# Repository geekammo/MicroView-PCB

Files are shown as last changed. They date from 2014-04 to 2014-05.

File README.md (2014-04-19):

MicroView: Chip-sized Arduino with built-in OLED Display!
================================
Designed by : [Geek Ammo](http://geekammo.com) & [SparkFun Electronics](http://www.sparkfun.com)

MicroView on finger

Summary
-------
The MicroView is the first chip-sized Arduino compatible that lets you see what your Arduino is thinking using a built-in OLED display.

Description
-----------
MicroView pinout

You've never seen an Arduino™ compatible like this. With a built-in OLED (Organic Light Emitting Diode Display) you can see what your Arduino is thinking without having to connect it to your computer. 

No more cryptic "Hello World" LED blink sequences or shoehorning oversized displays onto your tiny Arduino™. Development is much easier when you can see what's going on.

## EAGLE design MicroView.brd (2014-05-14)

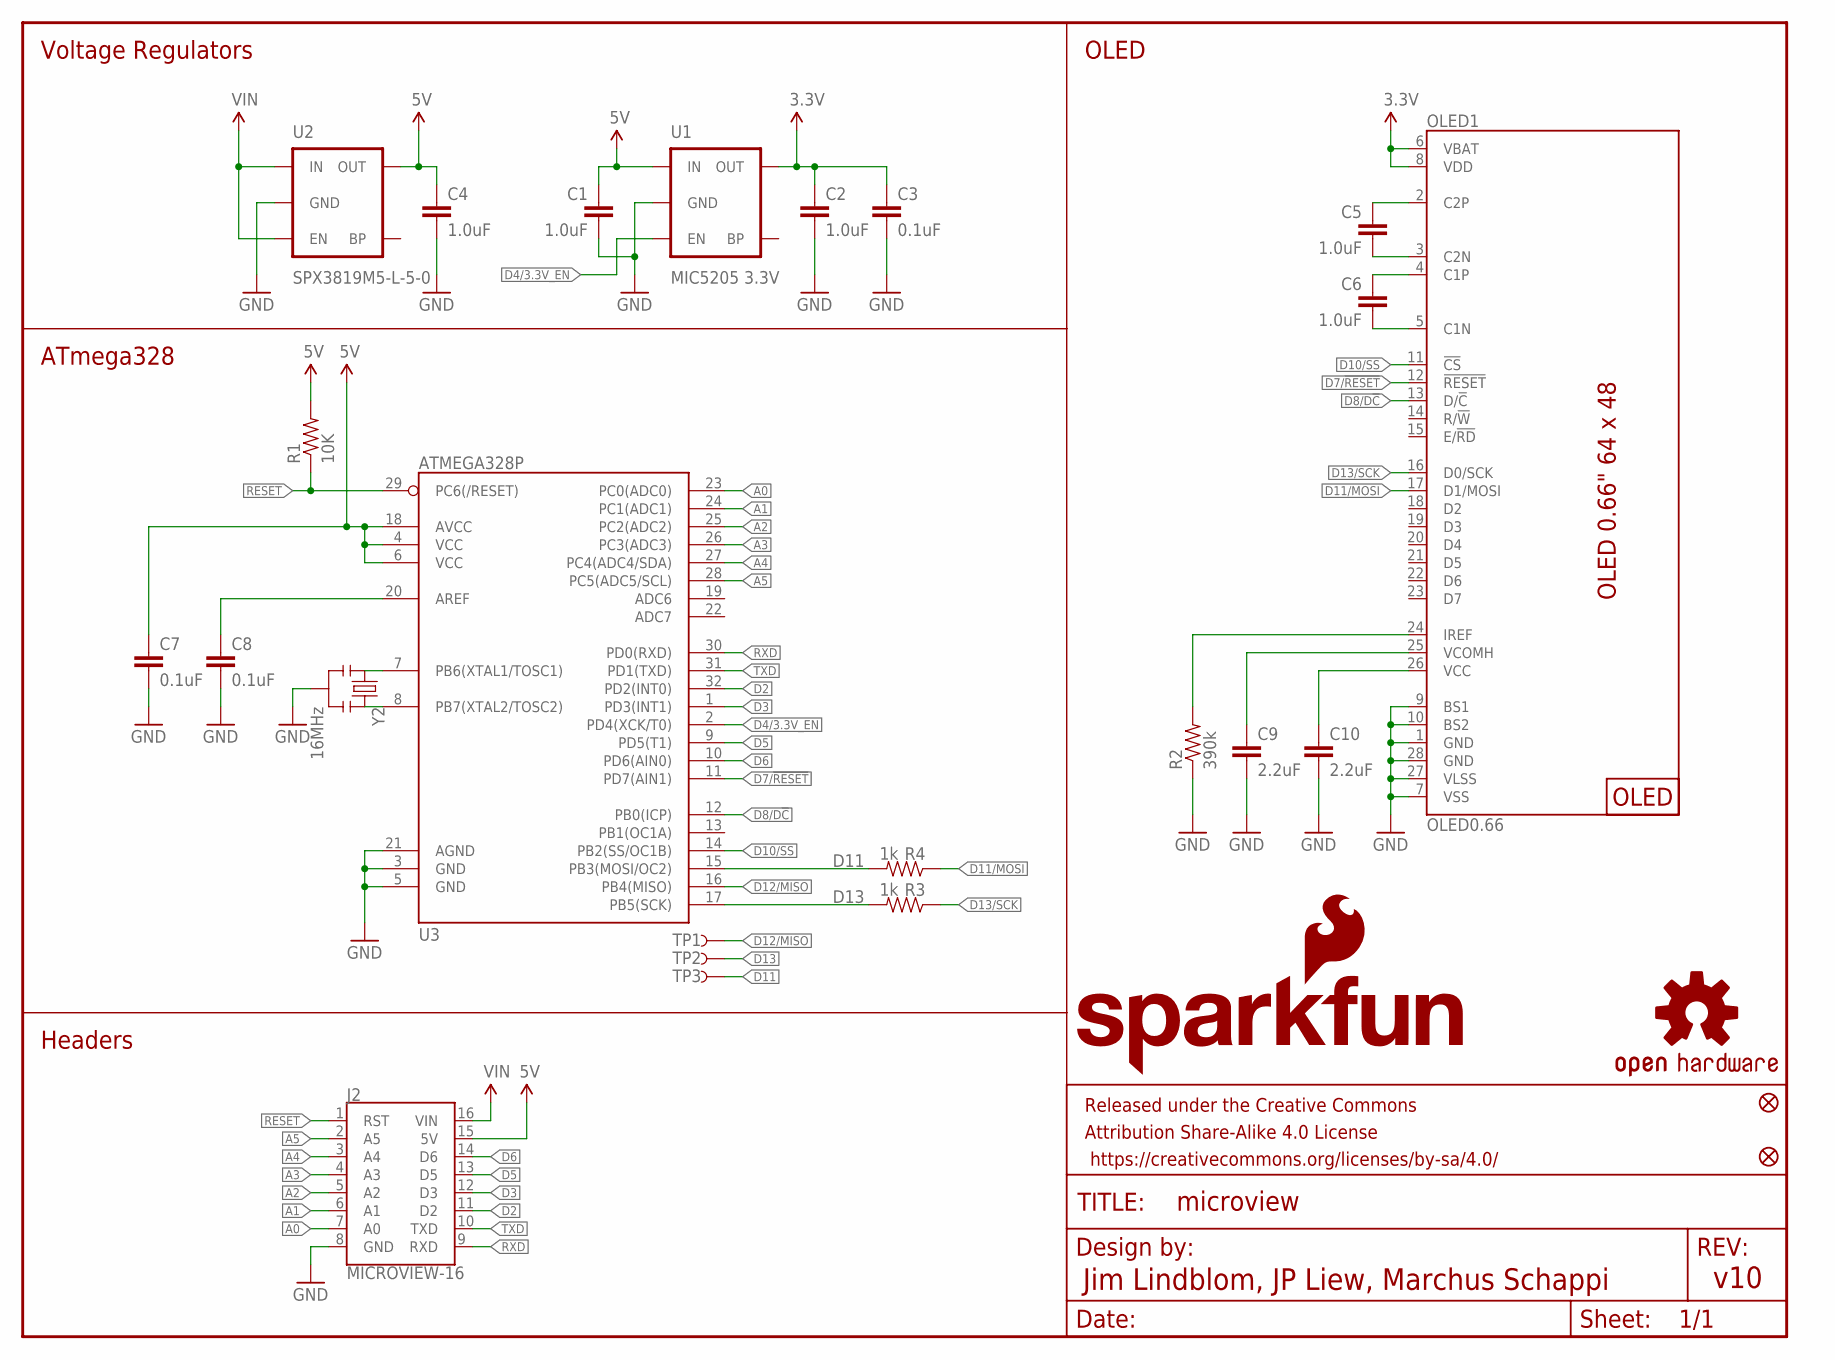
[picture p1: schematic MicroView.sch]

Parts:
C1, C2, C4, C5, C6: 1.0uF; 0603-CAP
C3, C7, C8: 0.1uF; 0603-CAP
C9, C10: 2.2uF; 0603-CAP
FID1, FID3: FIDUCIALUFIDUCIAL; MICRO-FIDUCIAL
FRAME1: FRAME-LETTER; CREATIVE_COMMONS
J1: OLED_SCREEN; OLED-SCREEN
J2: MICROVIEW-16; MV-DIP16
LOGO1: OSHW-LOGOS; OSHW-LOGO-S
LOGO4: SFE_LOGO_NAME_FLAME.1_INCH; SFE_LOGO_NAME_FLAME_.1
OLED1: OLED0.66; OLED-0.66-64X48
R1: 10K; 0603-RES
R2: 390k; 0603-RES
R3, R4: 1k; 0603-RES
TP1, TP2, TP3: TEST-POINT3X5; PAD.03X.05
U1: MIC5205 3.3V; SOT23-5
U2: SPX3819M5-L-5-0; SOT23-5
U3: ATMEGA328P; TQFP32-08
Y2: 16MHz; RESONATOR-SMD

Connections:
3.3V: C2.1, C3.1, OLED1.6 (VBAT), OLED1.8 (VDD), U1.5 (OUT)
5V: C1.1, C4.1, C7.1, J2.15 (5V), R1.2, U1.1 (IN), U2.5 (OUT), U3.4 (VCC), U3.6 (VCC), U3.18 (AVCC)
A0: J2.7 (A0), U3.23 (PC0(ADC0))
A1: J2.6 (A1), U3.24 (PC1(ADC1))
A2: J2.5 (A2), U3.25 (PC2(ADC2))
A3: J2.4 (A3), U3.26 (PC3(ADC3))
A4: J2.3 (A4), U3.27 (PC4(ADC4/SDA))
A5: J2.2 (A5), U3.28 (PC5(ADC5/SCL))
C1N: C6.2, OLED1.5 (C1N)
C1P: C6.1, OLED1.4 (C1P)
C2N: C5.2, OLED1.3 (C2N)
C2P: C5.1, OLED1.2 (C2P)
D2: J2.11 (D2), U3.32 (PD2(INT0))
D3: J2.12 (D3), U3.1 (PD3(INT1))
D4/3.3V_EN: U1.3 (EN), U3.2 (PD4(XCK/T0))
D5: J2.13 (D5), U3.9 (PD5(T1))
D6: J2.14 (D6), U3.10 (PD6(AIN0))
D7/!RESET!: OLED1.12 (!RESET!), U3.11 (PD7(AIN1))
D8/D!C!: OLED1.13 (D/!C!), U3.12 (PB0(ICP))
D10/SS: OLED1.11 (!CS!), U3.14 (PB2(SS/OC1B))
D11: R4.2, TP3.P$1, U3.15 (PB3(MOSI/OC2))
D11/MOSI: OLED1.17 (D1/MOSI), R4.1
D12/MISO: TP1.P$1, U3.16 (PB4(MISO))
D13: R3.2, TP2.P$1, U3.17 (PB5(SCK))
D13/SCK: OLED1.16 (D0/SCK), R3.1
GND: C1.2, C2.2, C3.2, C4.2, C7.2, C8.2, C9.2, C10.2, J2.8 (GND), OLED1.1 (GND), OLED1.7 (VSS), OLED1.9 (BS1), OLED1.10 (BS2), OLED1.27 (VLSS), OLED1.28 (GND), R2.1, U1.2 (GND), U2.2 (GND), U3.3 (GND), U3.5 (GND), U3.21 (AGND), Y2.2
unnamed: C10.1, OLED1.26 (VCC)
unnamed: C9.1, OLED1.25 (VCOMH)
unnamed: OLED1.24 (IREF), R2.2
unnamed: U3.7 (PB6(XTAL1/TOSC1)), Y2.1
unnamed: U3.8 (PB7(XTAL2/TOSC2)), Y2.3
unnamed: C8.1, U3.20 (AREF)
RESET: J2.1 (RST), R1.1, U3.29 (PC6(/RESET))
RXD: J2.9 (RXD), U3.30 (PD0(RXD))
TXD: J2.10 (TXD), U3.31 (PD1(TXD))
VIN: J2.16 (VIN), U2.1 (IN), U2.3 (EN)

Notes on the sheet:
v10
Jim Lindblom, JP Liew, Marchus Schappi
Voltage Regulators
ATmega328
OLED
Headers

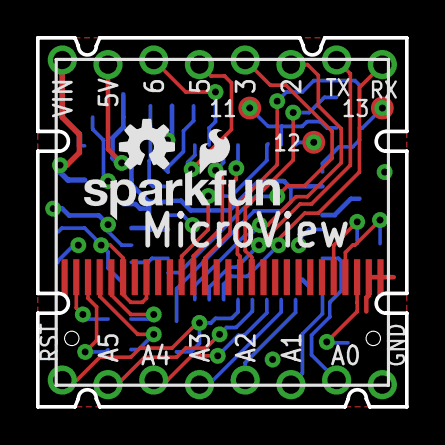
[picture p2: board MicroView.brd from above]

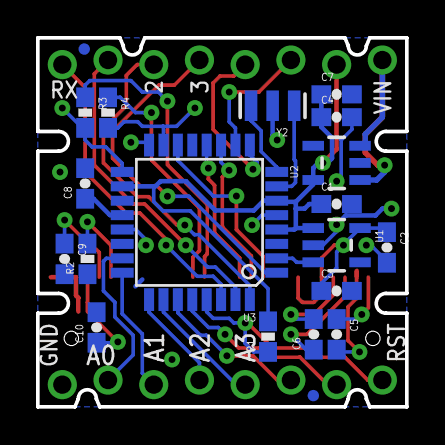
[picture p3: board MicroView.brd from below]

Board: 2 copper layers, 20.5 x 20.5 mm, 29 parts (20 on the bottom side), 36 nets.

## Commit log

2014-04-19 added images
    [MicroView.brd, MicroView.sch]
2014-04-19 v01 from SparkFun
    [MicroView.brd, MicroView.sch]
2014-04-19 v02 from SparkFun
    [MicroView.brd, MicroView.sch]
2014-05-14 Production Final version V10
    [MicroView.brd, MicroView.sch]

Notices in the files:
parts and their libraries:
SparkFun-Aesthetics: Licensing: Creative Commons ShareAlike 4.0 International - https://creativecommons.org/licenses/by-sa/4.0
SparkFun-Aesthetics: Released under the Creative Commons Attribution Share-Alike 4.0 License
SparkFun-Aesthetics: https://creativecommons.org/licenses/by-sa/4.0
